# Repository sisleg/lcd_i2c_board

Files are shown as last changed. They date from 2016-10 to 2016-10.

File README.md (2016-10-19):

A small interface bord used to connect a LCD character or a OLed character
display that uses the classic HD44780 protocol. Via a I2C buss to any microcontroller.

A MCP23017 from Microchip is used. That ccontroller has two 8 bit ports. One is 
used as the databus to the Display. The other port is used for controll lines (3 bits), contoling a backlight or a external led (1 bit). The last four bits is
used for a simple keybord interface.

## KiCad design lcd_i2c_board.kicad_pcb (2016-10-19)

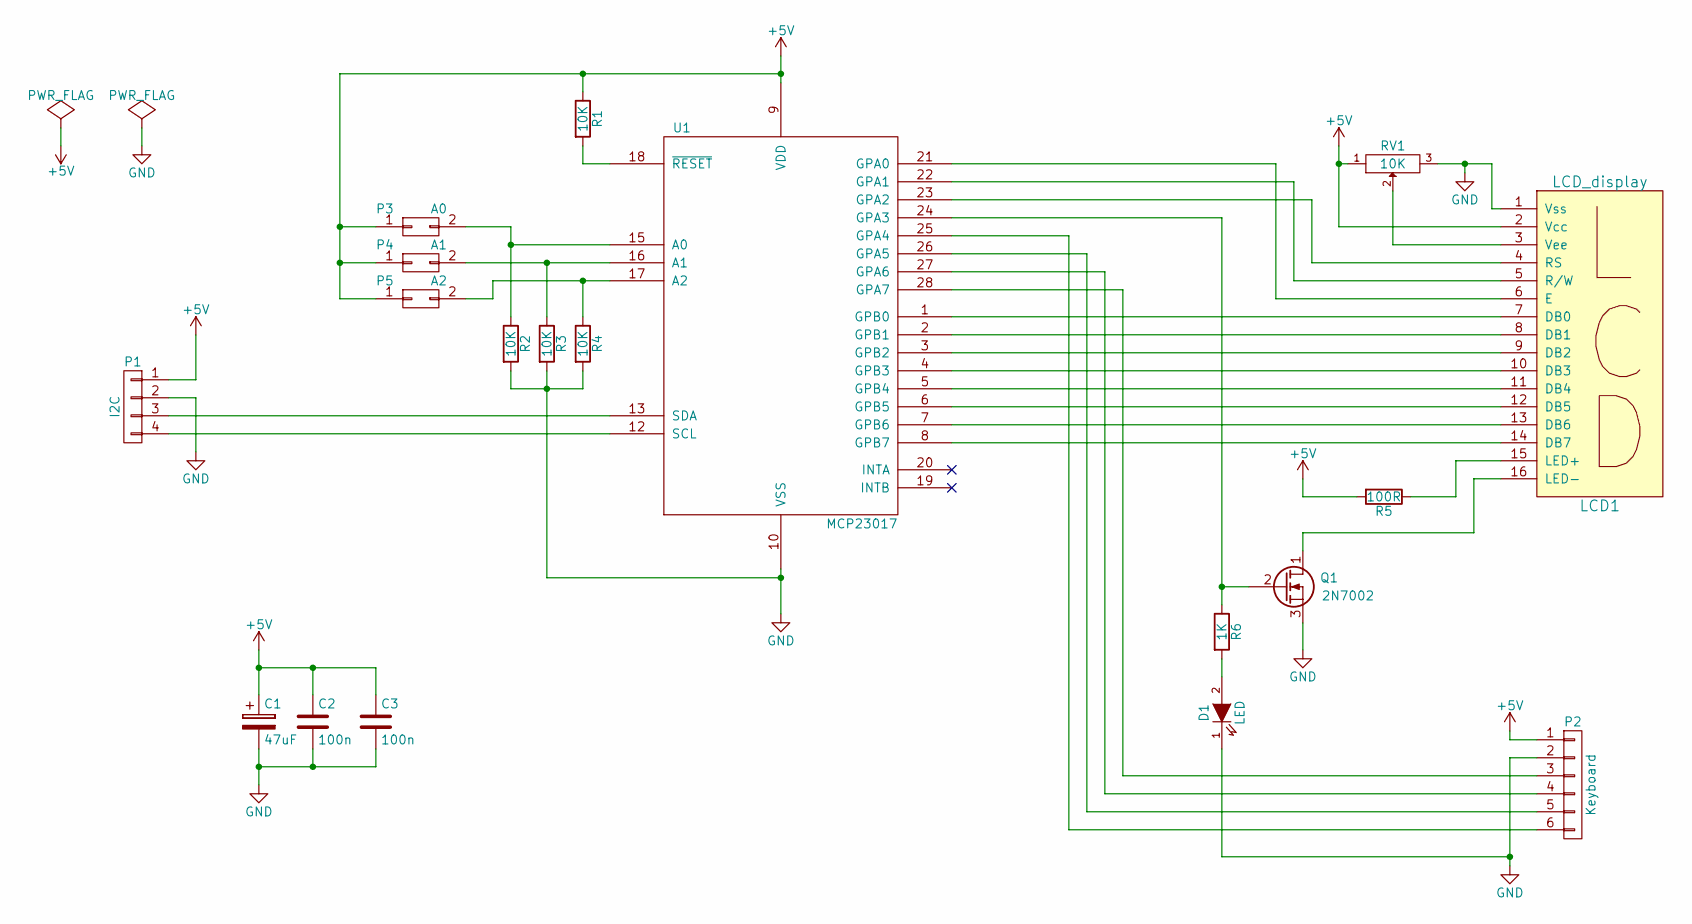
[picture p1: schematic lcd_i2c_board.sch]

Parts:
C1: 47uF; c_elec_6.3x7.7
C2, C3: 100n; C_1206_HandSoldering
D1: LED; MOLEX-22-05-3021
LCD1: LCD_display; Pin_Header_Straight_1x16
P1: I2C; MOLEX-22-05-3041
P2: Keyboard; MOLEX-22-05-3061
P3: A0; R_0805_HandSoldering
P4: A1; R_0805_HandSoldering
P5: A2; R_0805_HandSoldering
Q1: 2N7002; SOT-23_Handsoldering
R1, R2, R3, R4: 10K; R_0805_HandSoldering
R5: 100R; R_0805_HandSoldering
R6: 1K; R_0805_HandSoldering
RV1: 10K; Potentiometer_Trimmer-Suntan-TSR-3386P
U1: MCP23017; SOIC-28W_7.5x17.9mm_Pitch1.27mm

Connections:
+5V: C1.1, C2.1, C3.1, LCD1.2 (Vcc), P1.1, P2.1, P3.1, P4.1, P5.1, R1.1, R5.2, RV1.1, U1.9 (VDD)
GND: C1.2, C2.2, C3.2, D1.1 (K), LCD1.1 (Vss), P1.2, P2.2, Q1.3 (S), R2.2, R3.2, R4.2, RV1.3, U1.10 (VSS)
unnamed: D1.2 (A), R6.2
unnamed: LCD1.3 (Vee), RV1.2
unnamed: LCD1.4 (RS), U1.23 (GPA2)
unnamed: LCD1.5 (R/W), U1.22 (GPA1)
unnamed: LCD1.6 (E), U1.21 (GPA0)
unnamed: LCD1.7 (DB0), U1.1 (GPB0)
unnamed: LCD1.8 (DB1), U1.2 (GPB1)
unnamed: LCD1.9 (DB2), U1.3 (GPB2)
unnamed: LCD1.10 (DB3), U1.4 (GPB3)
unnamed: LCD1.11 (DB4), U1.5 (GPB4)
unnamed: LCD1.12 (DB5), U1.6 (GPB5)
unnamed: LCD1.13 (DB6), U1.7 (GPB6)
unnamed: LCD1.14 (DB7), U1.8 (GPB7)
unnamed: LCD1.15 (LED+), R5.1
unnamed: LCD1.16 (LED-), Q1.1 (D)
unnamed: P1.3, U1.13 (SDA)
unnamed: P1.4, U1.12 (SCL)
unnamed: P2.3, U1.28 (GPA7)
unnamed: P2.4, U1.27 (GPA6)
unnamed: P2.5, U1.26 (GPA5)
unnamed: P2.6, U1.25 (GPA4)
unnamed: P3.2, R2.1, U1.15 (A0)
unnamed: P4.2, R3.1, U1.16 (A1)
unnamed: P5.2, R4.1, U1.17 (A2)
unnamed: Q1.2 (G), R6.1, U1.24 (GPA3)
unnamed: R1.2, U1.18 (~RESET)

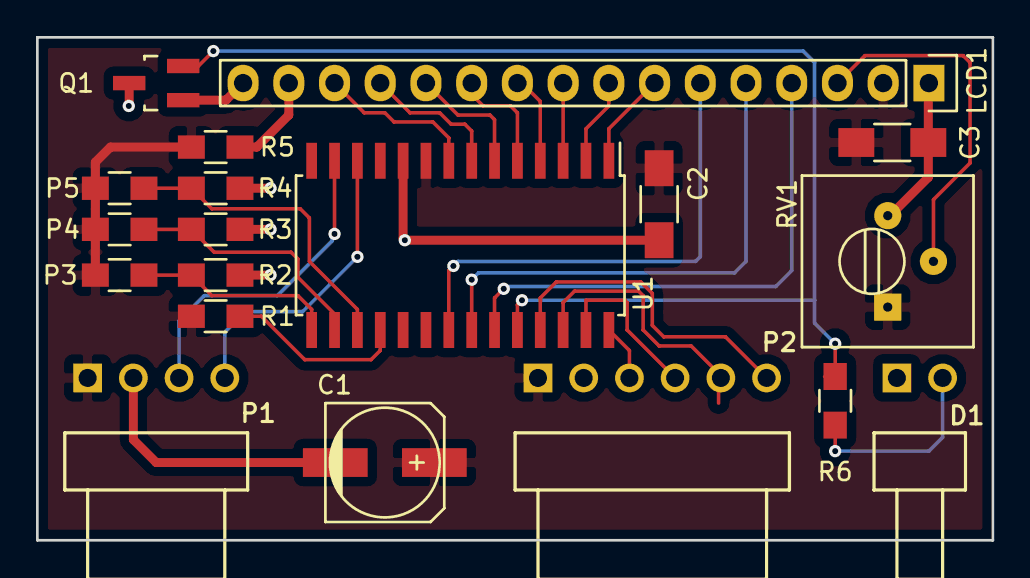
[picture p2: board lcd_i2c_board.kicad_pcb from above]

Board: 2 copper layers, 53.1 x 27.9 mm, 19 parts (0 on the bottom side), 28 nets.

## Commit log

2016-10-19 First commit, an order to OSH Park is done using this release.
    [lcd_i2c_board.kicad_pcb, lcd_i2c_board.sch]
2016-10-19 Change reference placement because component values did not show up on OSH park board.
    [lcd_i2c_board.kicad_pcb]
